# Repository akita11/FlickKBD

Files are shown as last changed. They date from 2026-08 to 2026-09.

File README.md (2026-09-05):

# FlickKBD

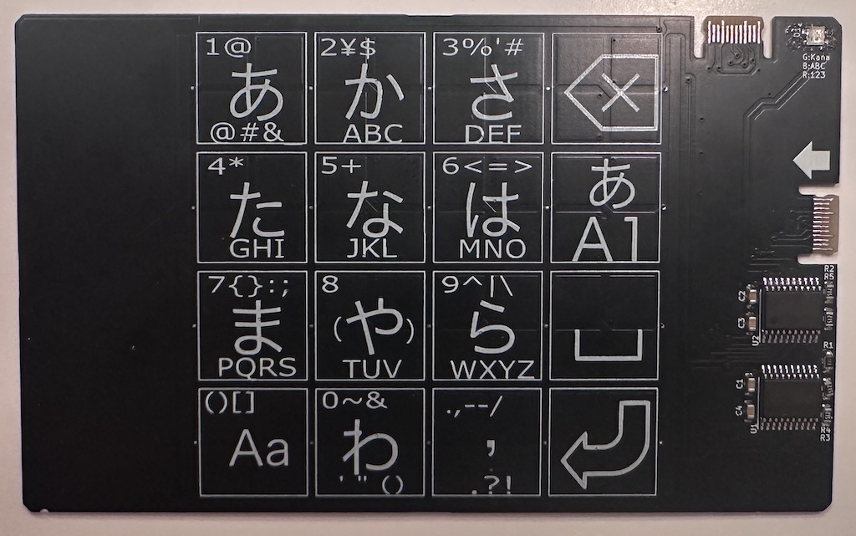
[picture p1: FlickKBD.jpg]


静電容量式タッチ検出を使った名刺サイズのフリック入力キーボードです。PC等にUSB(Type-C)で接続し、キーボードとして使うことができます。
かな（ローマ字入力）、英字、数字の3つのモードがあります。

※感度・入力速度はサポートページ内の動画からご確認ください。スマホのフリック入力ほどの実用性はありませんのでご了承ください。またPC等側のキーボードの設定（英字キーボード等）によっては、表示されているものと異なる文字が入力されることがあります。またタッチ検出の補正動作によって、非タッチ時にタッチが検出されてLEDが消灯している場合は、少し待つとLEDが点灯して入力できるようになります。

[動作原理と使用例（動画）(ProtoPedia)](https://protopedia.net/prototype/9148)

## 使い方

本機のUSB Type-Cコネクタ（基板と一体化）にUSB Type-Cケーブルを刺し、PC等に接続します。
PC等からはUSBキーボードとして認識されます。
（本機には2つのUSBコネクタがありますが、どちらでもOKです）

### 文字入力

やや強めにタッチしつつゆっくり移動させてフリック入力ができます。
（カッコ内は、左上のキーの場合の入力される文字例）

- タッチのみ: 基本文字（"a"）
- タッチ後、左にマス目の半分ほど移動：左フリック（"i"）
- タッチ後、上にマス目の半分ほど移動：上フリック（"u"）
- タッチ後、右にマス目の半分ほど移動：上フリック（"e"）
- タッチ後、下にマス目の半分ほど移動：上フリック（"o"）

LED表示は以下の意味で、タッチやフリック動作の検出状況を確認できます。
- 非タッチ時に点灯
- タッチ時に消灯
- 左or右フリック検出時に1回点滅
- 上or下フリック検出時に2回点滅、

なお、かな（ローマ字）入力モード時に"A/a"キー（左下）を押してから（LEDがやや暗くなる）文字入力を行うと小文字が入力されます。（例："あ(a)"→"ぁ(xa)"

また、アルファベット入力モード時に"A/a"キー（左下）を押すと、大文字／小文字モードが切り替わります（小文字入力時はLEDがやや暗くなります）

### 入力モード

"あA1"キー（右端上から2つめ）を押すと、入力モードが切り替わり、以下のようにLEDの色が変わります。

- かな（ローマ字）入力モード: 緑
- アルファベット入力モード: 青
- 数字・記号入力モード: 赤

## プログラムの書き換え

ArduinoIDEに、[CH55xduino](https://github.com/DeqingSun/ch55xduino)をインストールし、2つのUSBコネクタからそれぞれのマイコン(CH552)に書き込みます。
事前に、TouchKey.{c,h}を、ArduinoIDEフォルダ内のCH55xduinoフォルダのTouchKey/srcにコピーしてださい（念のため、オリジナルのCH55xduinoの両ファイルはバックアップをとっておいてください）。
（Macの場合は、~/Library/Arduino15/packages/CH55xDuino/hardware/mcs51/0.0.26/libraries/TouchKey/src）
- USB Settingを"USER CODE w/128B USB RAM"に変更
- 上側のUSBコネクタ: FlickKBD.ino中の"#define DEV_R"をコメントアウトし、書き込み
- 右側のUSBコネクタ: FlickKBD.ino中の"#define DEV_R"を残して、書き込み

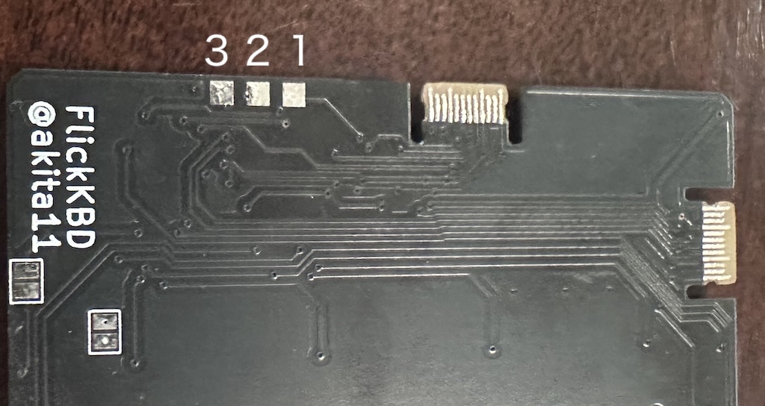
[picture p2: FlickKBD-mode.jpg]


なおブランクのCH552に初回書き込み時以外は、CH552を、以下の手順でダウンロードモードに設定してください。
- 右側のUSBコネクタ使用時: 裏面の上図の"1-2"間をジャンパ線等でショートした状態で右側USBコネクタに接続し、1秒ほど保持してからショートを解除する
- 上側のUSBコネクタ使用時: 裏面の上図の"2-3"間をジャンパ線等でショートした状態で右側USBコネクタに接続し、1秒ほど保持してからショートを解除する

## Author

Junichi Akita (akita@ifdl.jp / @akita11)

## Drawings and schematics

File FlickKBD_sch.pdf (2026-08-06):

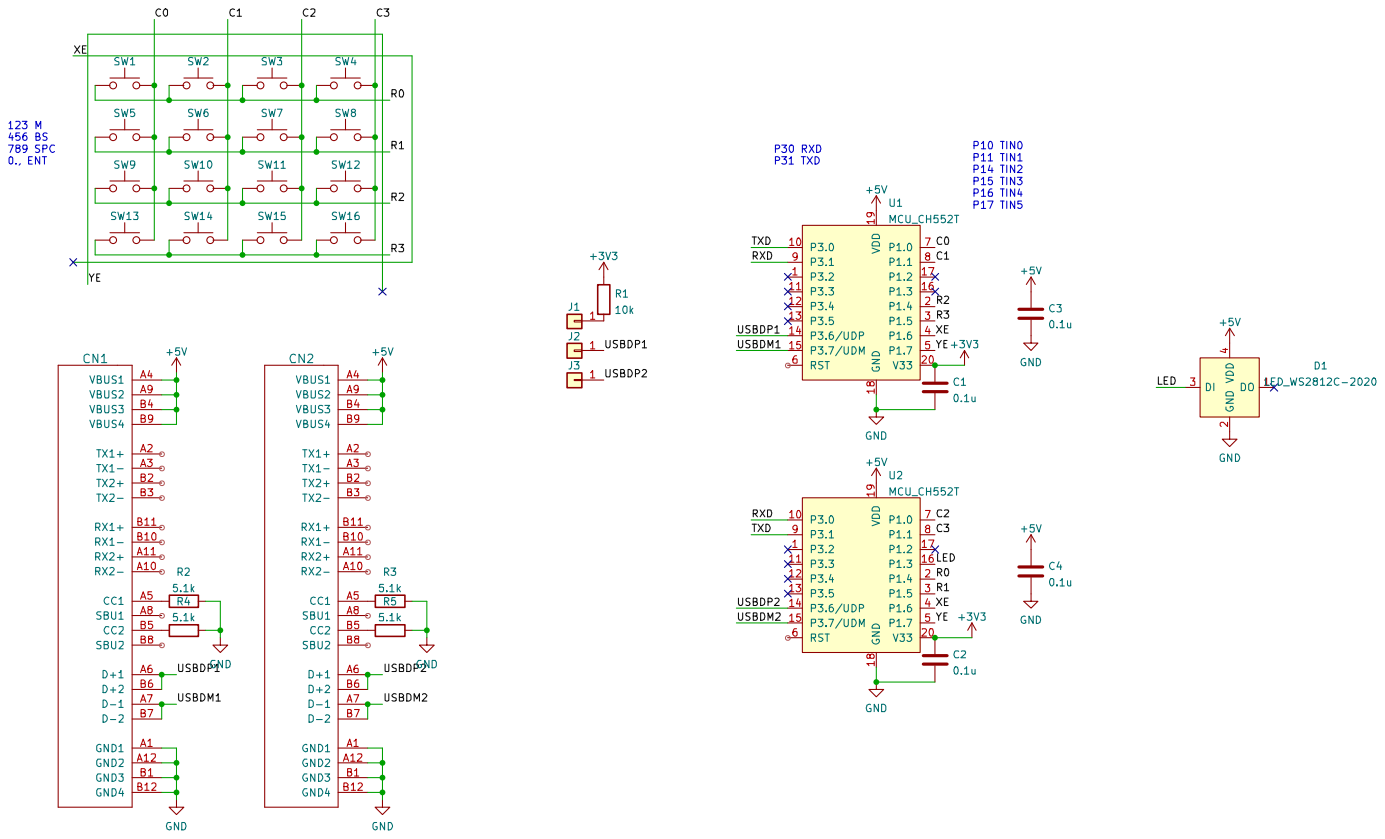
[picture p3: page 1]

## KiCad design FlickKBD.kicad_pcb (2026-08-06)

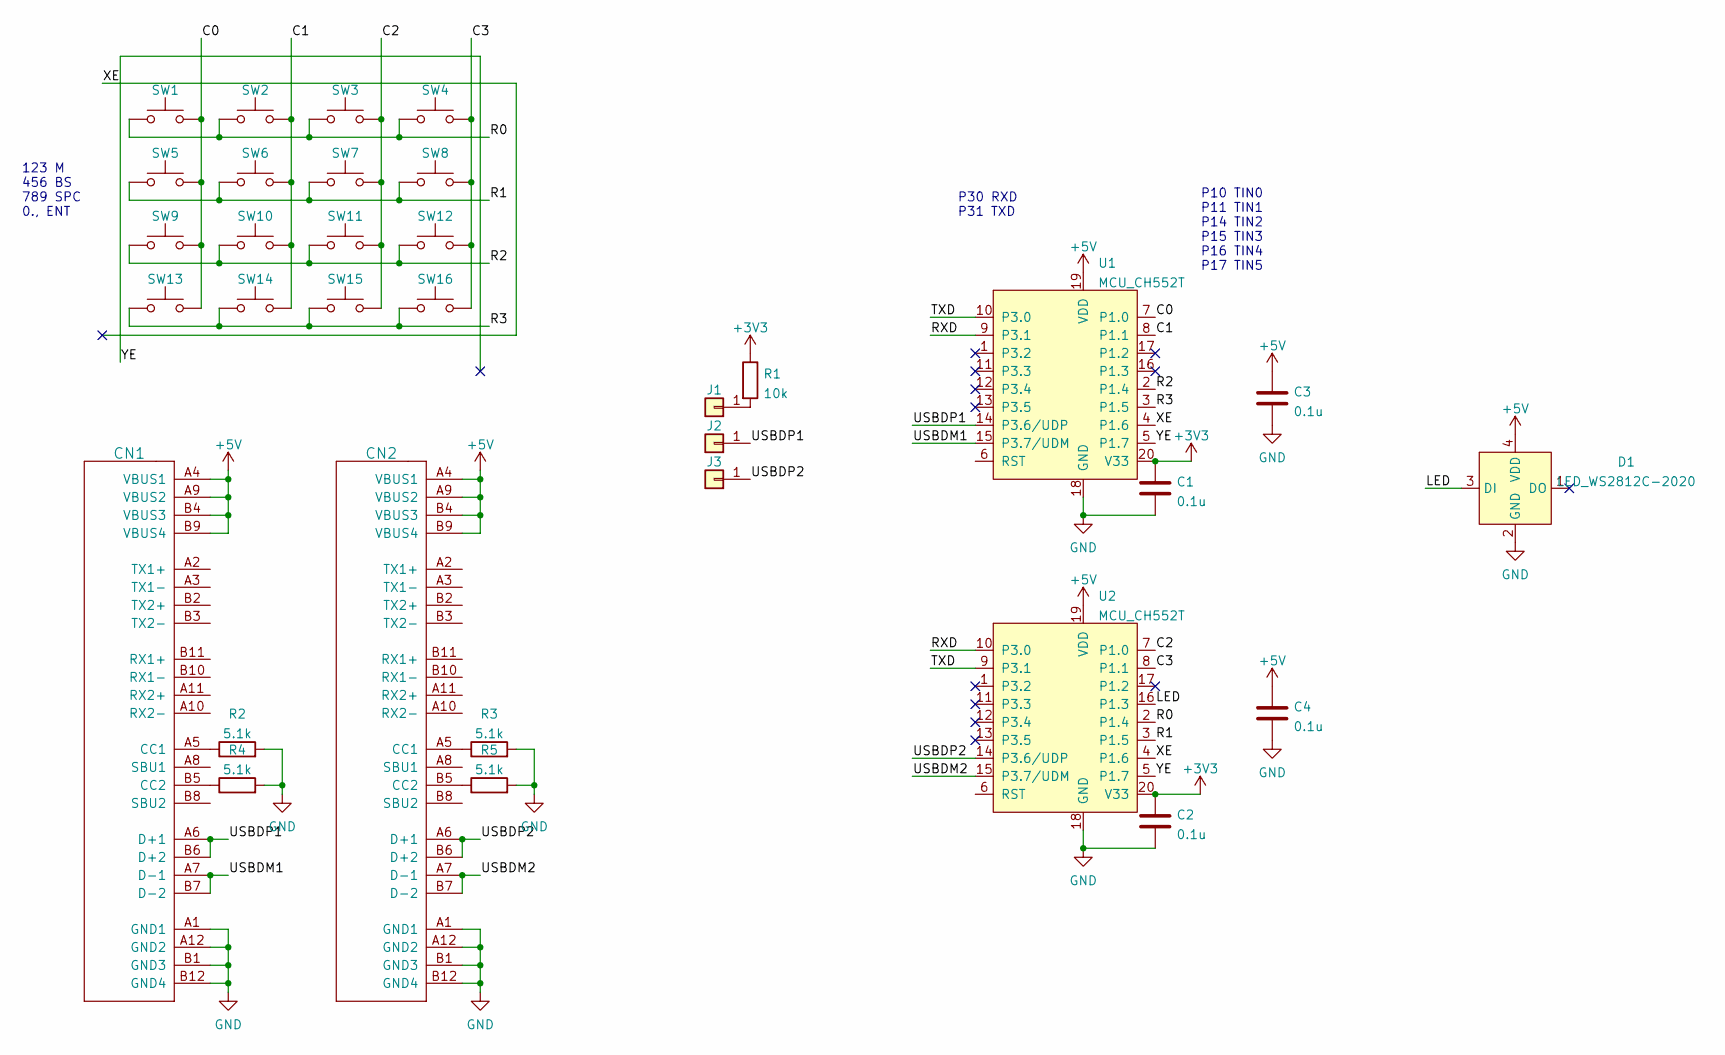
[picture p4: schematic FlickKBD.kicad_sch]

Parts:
C1, C2, C3, C4: 0.1u; C_0603_1608Metric
CN1, CN2: CON_USB-CPCBPLUG; USB-C_PCBPLUG
D1: LED_WS2812C-2020; LED_2020_4p
J1, J2, J3: Conn_01x01; Pad_SMD1.6mm
R1: 10k; R_0603_1608Metric
R2, R3, R4, R5: 5.1k; R_0603_1608Metric
SW1, SW2, SW3, SW4, SW5, SW6, SW7, SW8, SW9, SW10, SW11, SW12, SW13, SW14, SW15, SW16: SW_Push; SMD_Key_11mmX_p13mm
U1, U2: MCU_CH552T; TSSOP-20_4.4x6.5mm_P0.65mm

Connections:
+3V3: C1.1, C2.1, R1.1, U1.20 (V33), U2.20 (V33)
+5V: C3.1, C4.1, CN1.A4 (VBUS1), CN1.A9 (VBUS2), CN1.B4 (VBUS3), CN1.B9 (VBUS4), CN2.A4 (VBUS1), CN2.A9 (VBUS2), CN2.B4 (VBUS3), CN2.B9 (VBUS4), D1.4 (VDD), U1.19 (VDD), U2.19 (VDD)
/C0: SW1.1, SW5.1, SW9.1, SW13.1, U1.7 (P1.0)
/C1: SW2.1, SW6.1, SW10.1, SW14.1, U1.8 (P1.1)
/C2: SW3.1, SW7.1, SW11.1, SW15.1, U2.7 (P1.0)
/C3: SW4.1, SW8.1, SW12.1, SW16.1, U2.8 (P1.1)
/LED: D1.3 (DI), U2.16 (P1.3)
/R0: SW1.2, SW2.2, SW3.2, SW4.2, U2.2 (P1.4)
/R1: SW5.2, SW6.2, SW7.2, SW8.2, U2.3 (P1.5)
/R2: SW9.2, SW10.2, SW11.2, SW12.2, U1.2 (P1.4)
/R3: SW13.2, SW14.2, SW15.2, SW16.2, U1.3 (P1.5)
/RXD: U1.9 (P3.1), U2.10 (P3.0)
/TXD: U1.10 (P3.0), U2.9 (P3.1)
/USBDM1: CN1.A7 (D-1), CN1.B7 (D-2), U1.15 (P3.7/UDM)
/USBDM2: CN2.A7 (D-1), CN2.B7 (D-2), U2.15 (P3.7/UDM)
/USBDP1: CN1.A6 (D+1), CN1.B6 (D+2), J2.1, U1.14 (P3.6/UDP)
/USBDP2: CN2.A6 (D+1), CN2.B6 (D+2), J3.1, U2.14 (P3.6/UDP)
/XE: U1.4 (P1.6), U2.4 (P1.6); also elsewhere on the board
/YE: U1.5 (P1.7), U2.5 (P1.7); also elsewhere on the board
GND: C1.2, C2.2, C3.2, C4.2, CN1.A1 (GND1), CN1.A12 (GND2), CN1.B1 (GND3), CN1.B12 (GND4), CN2.A1 (GND1), CN2.A12 (GND2), CN2.B1 (GND3), CN2.B12 (GND4), D1.2 (GND), R2.2, R3.2, R4.2, R5.2, U1.18 (GND), U2.18 (GND)
unnamed: CN1.A5 (CC1), R2.1
unnamed: CN1.B5 (CC2), R4.1
unnamed: CN2.A5 (CC1), R3.1
unnamed: CN2.B5 (CC2), R5.1
unnamed: J1.1, R1.2

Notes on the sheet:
P10 TIN0 P11 TIN1 P14 TIN2 P15 TIN3 P16 TIN4 P17 TIN5
123 M 456 BS 789 SPC 0., ENT
P30 RXD P31 TXD

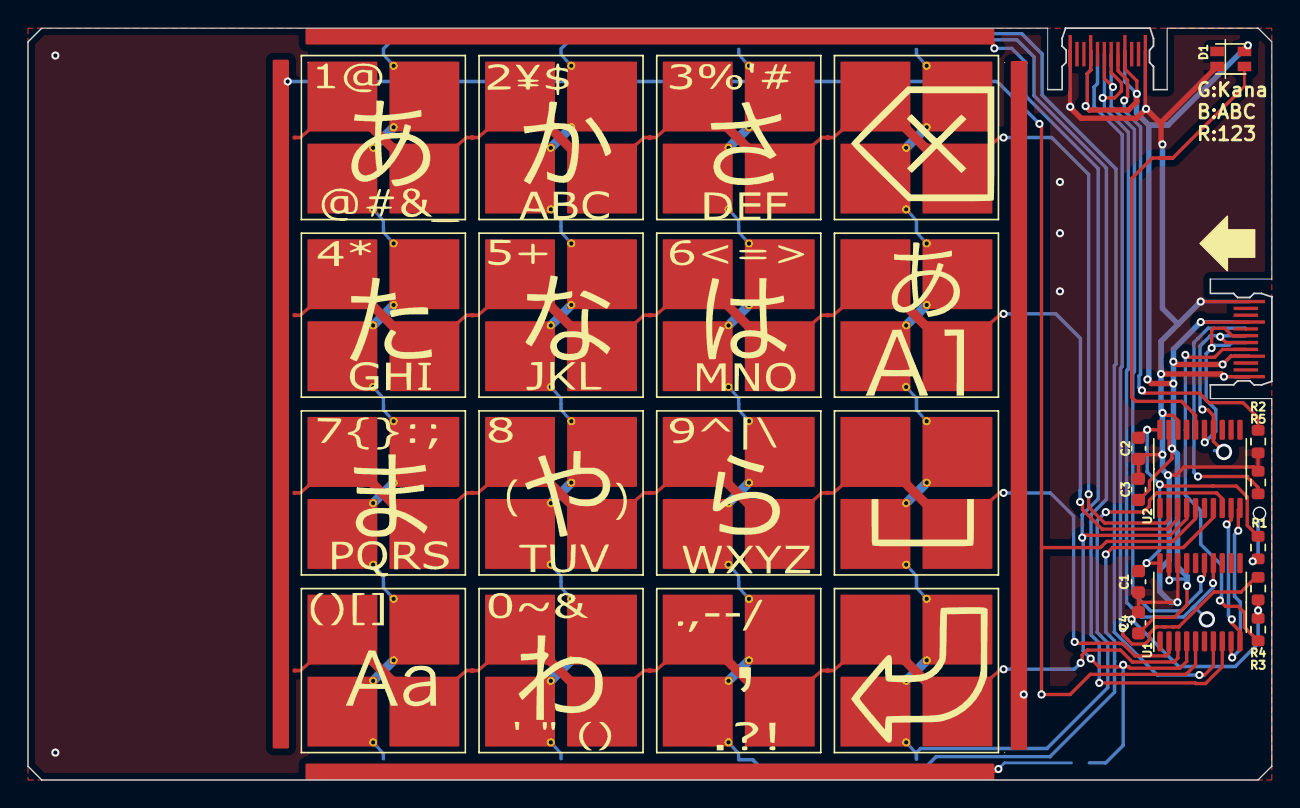
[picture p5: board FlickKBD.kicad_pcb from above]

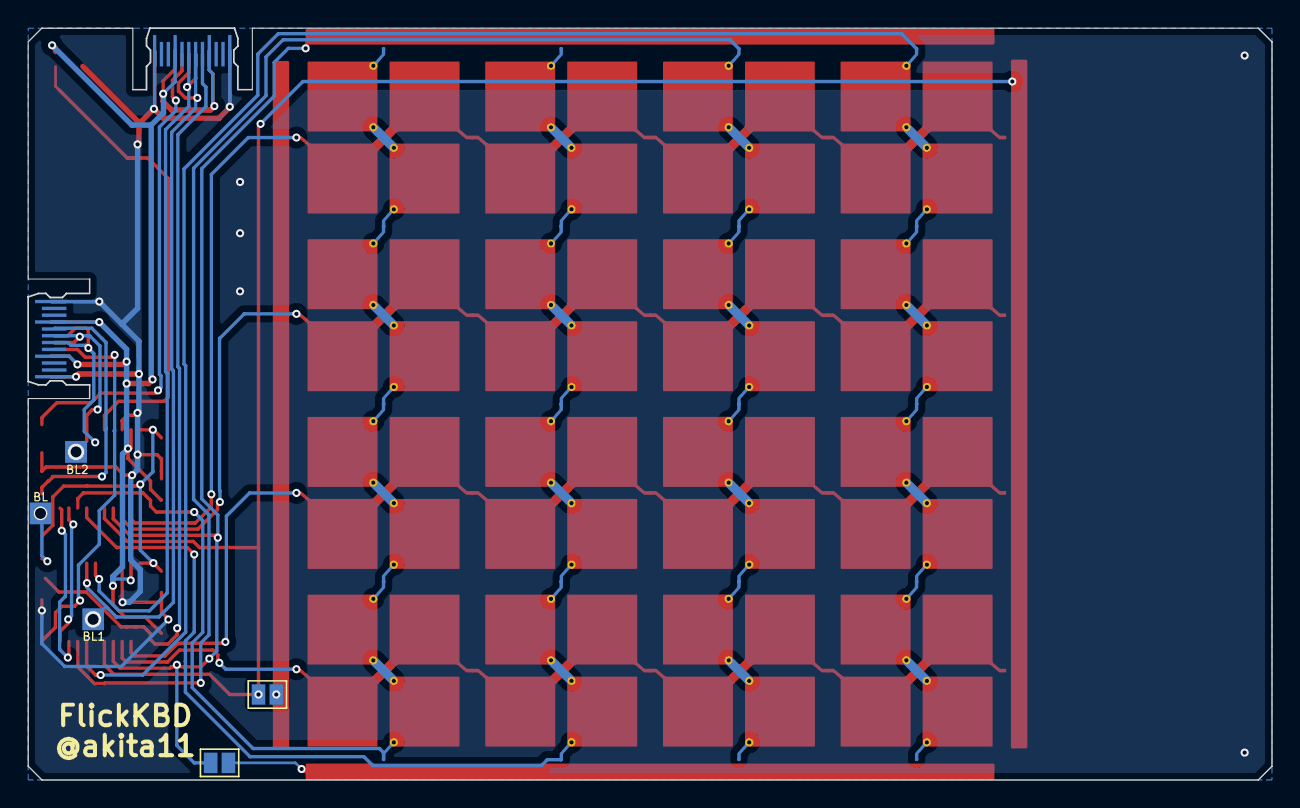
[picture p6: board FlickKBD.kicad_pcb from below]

Board: 2 copper layers, 91.0 x 55.0 mm, 35 parts (5 on the bottom side), 25 nets.

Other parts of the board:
JP1, JP2: Jumper_2_Open; SolderJumper-2_P1.3mm_Open_Pad1.0x1.5mm

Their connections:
/XE: JP1.1 (A); also elsewhere on the board
/YE: JP2.1 (A); also elsewhere on the board

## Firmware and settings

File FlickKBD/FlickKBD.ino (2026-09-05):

//#define DEV_R // for 1st CH552 (U2), with LED
#define USBKBD
// when building without USBKBD defined, src/userUsbHidKeyboard must be moved outside the Sketch folder.
//#define DEBUG // for touch parameter tuning

#include <TouchKey.h>

#ifdef DEV_R
#include <WS2812.h>
__xdata uint8_t ledData[3];
void setLED(uint8_t r, uint8_t g, uint8_t b){
  set_pixel_for_GRB_LED(ledData, 0, r, g, b);
  neopixel_show_P1_3(ledData, 3);
}
#endif

// 文字モード: ローマ字かな -> アルファベット -> 数字 の循環トグル (C3/R1)
#define MODE_KANA  0
#define MODE_ALPHA 1
#define MODE_NUM   2
uint8_t charMode = MODE_KANA;
// アルファベットモード:大文字(1)/小文字(0)、かなモード:通常(1い)/小文字モード(0)
// (どちらもC0/R3で切替、LEDは明(1)/暗(0))
uint8_t altKeyUpper = 1;

#ifdef DEV_R
#define LED_BRIGHT 10
#define LED_DIM     2

// 普段点灯するモード色 (かな=緑/アルファベット=青/数字=赤)、
// かな/アルファベットモードはaltKeyUpperで明暗
void showIdleLED(){
  uint8_t bright = ((charMode == MODE_ALPHA || charMode == MODE_KANA) && !altKeyUpper) ? LED_DIM : LED_BRIGHT;
  if (charMode == MODE_KANA) setLED(0, bright, 0);
  else if (charMode == MODE_ALPHA) setLED(0, 0, bright);
  else setLED(bright, 0, 0);
}

// タッチ検出時: 消灯
void ledTouchOff(){
  setLED(0, 0, 0);
}

// 左右フリック=1回、上下フリック=2回、普段の色でcount回点滅し、
// (タッチ中のため)消灯状態に戻る。離す時にshowIdleLED()で点灯に戻す。
void blinkLED(uint8_t count){
  uint8_t bright = ((charMode == MODE_ALPHA || charMode == MODE_KANA) && !altKeyUpper) ? LED_DIM : LED_BRIGHT;
  for (uint8_t i = 0; i < count; i++){
    if (charMode == MODE_KANA) setLED(0, bright, 0);
    else if (charMode == MODE_ALPHA) setLED(0, 0, bright);
    else setLED(bright, 0, 0);
    delay(80);
    setLED(0, 0, 0u);
    delay(80);
  }
}
#else
void showIdleLED(){}
void ledTouchOff(){}
void blinkLED(uint8_t count){}
#endif

#ifdef USBKBD
  #ifndef USER_USB_RAM
  #error "This example needs to be compiled with a USER USB setting"
  #endif
  #include "src/userUsbHidKeyboard/USBHIDKeyboard.h"
#endif

//       T0 T1 T2 T3 T4 T5 
// DevU: C0 C1 R2 R3 XE YE (USB conn: UP)
// DevR: C2 C3 R0 R1 XE YE (USB conn: RIGHT)

// X------------------ (U4/R4)
//         U0 U1 R0 R1 
// Y       C0 C1 C2 C3 Y(U5/R5)
// | R2 R0       r  r  |
// | R3 R1       r  r  |
// | U2 R2 u  u        |
// | U3 R3 u  u        |
// X------------------

// ============================================================
// TouchKey.c への修正まとめ (2025-07-17)
//
// 【問題1】TIN5/TIN6 が非タッチ時でもタッチ状態のままになる
//   原因A: TouchKey_begin() でポーリングモードにより baseline を初期化するが、
//          ISR 連続スキャンモードでの計測値と TIN5/TIN6 だけ大きくずれる
//          (TIN5: +659差、TIN6: -258差)。TIN6 は起動直後から touchThreshold を
//          超えた状態でスタートし、以後ずっとタッチ判定になる。
//   原因B: baseline の追跡速度 (noiseHalfDelta/noiseCountLimit = 0.2 units/cycle) が
//          TIN5/TIN6 の環境ドリフト速度 (~6 units/cycle) に追いつかない。
//
//   修正1 (TouchKey_begin): IE_TKEY = 1 で ISR を起動した後、2完全スキャンサイクル
//          (12 ISR イベント) 待機し、ISR モードの実計測値で baseline を上書きする。
//          これにより初期ズレが解消され、以後の漸進的ドリフトは Case1 で追跡できる。
//
//   修正2 (TouchKey_Process): touchStuckLimit サイクル (デフォルト500 ≒ 6秒) 以上
//          タッチ状態が続いた場合、baseline を raw に向けて通常より大きく移動させる
//          強制補正機構 (スタックタッチ回復) を追加。修正1 のフォールバックとして機能。
//
// 【問題2】TIN0-3 でタッチを離した後、数秒間タッチ検知が続く
//   原因: タッチ中に Case2 の slow tracking が baseline を少し下方へ移動させる。
//         指を離すと raw はすぐにアンビエントへ戻り raw > baseline (diff > 0) になるが、
//         解除条件が "mdiff > 0 && mdiff < releaseThreshold" であるため、
//         mdiff = 0 の状態では解除条件を満たせない。
//         以後 Case2 upward tracking が baseline をゆっくり引き上げ (~0.2 units/cycle)、
//         数秒後にノイズで mdiff が 1 になって初めて解除される。
//
//   修正3 (TouchKey_Process): タッチ中 (touchKeyPressed セット済み) に diff > 0
//          (raw が baseline を上回った) を検出したとき即座に解除し、baseline を raw に
//          スナップする。CH552 ではタッチ = raw 低下なので、raw が baseline を超えた
//          時点でタッチ終了は確実。タッチ中に raw が baseline を超えるほどの
//          ノイズは実質起きないため誤検出のリスクはない。
// ============================================================

extern volatile __xdata uint16_t touchRawValue[];
extern __xdata uint16_t touchBaseline[];
extern __xdata uint16_t touchMaxHalfDelta;
extern __xdata uint16_t touchThreshold[6];
extern __xdata uint16_t releaseThreshold[6];
extern __xdata uint16_t touchStuckLimit[6];
extern __xdata uint8_t touchNextCalibrateCycleCounter;
extern __xdata uint8_t touchCycleCounter;

uint8_t touchU = 0;
uint8_t touchR = 0;

uint16_t touch_c = 0;
uint16_t touch_p = 0;

#define COL0 0x001
#define COL1 0x002
#define COL2 0x004
#define COL3 0x008
#define COLY 0x100
#define ROW0 0x010
#define ROW1 0x020
#define ROW2 0x040
#define ROW3 0x080
#define ROWX 0x200
#define COLALL (COL0 | COL1 | COL2 | COL3 | COLY)
#define ROWALL (ROW0 | ROW1 | ROW2 | ROW3 | ROWX)

void setup() {
  // 起動直後、他の初期化より前に明示的にモード色(かな=緑,LED_BRIGHT)を点灯し、
  // 未初期化状態のLEDが誤って明るく見える時間を最小化する
  showIdleLED();
#ifdef DEV_R
  pinMode(13, OUTPUT);
  TouchKey_begin( (1 << 0) | (1 << 1) | (1 << 2) | (1 << 3) | (1 << 4) | (1 << 5) ); //Enable all 6 channels: TIN0(P1.0), TIN1(P1.1), TIN2(P1.4), TIN3(P1.5), TIN4(P1.6), TIN5(P1.7)
#else
  TouchKey_begin( (1 << 0) | (1 << 1) | (1 << 2) | (1 << 3) | (1 << 4) | (1 << 5) ); //Enable all 6 channels: TIN0(P1.0), TIN1(P1.1), TIN2(P1.4), TIN3(P1.5), TIN4(P1.6), TIN5(P1.7)
//  TouchKey_begin( (1 << 0) | (1 << 1) | (1 << 2) | (1 << 3) ); //Enable all 6 channels: TIN0(P1.0), TIN1(P1.1), TIN2(P1.4), TIN3(P1.5)
#endif
#ifdef DEV_R
/*
  // for v1
  TouchKey_SetMaxHalfDelta(20);    //MHD=5, increase if sensor value are more noisy
  TouchKey_SetNoiseHalfDelta(2);    //NHD=2, If baseline need to adjust at higher rate, increase this value
  TouchKey_SetNoiseCountLimit(10);  //NCL=10, If baseline need to adjust faster, increase this value
//  TouchKey_SetFilterDelayLimit(5);  //FDL=5, make overall adjustment slower
  TouchKey_SetTouchThreshold(1500);  //100, Bigger touch pad can use a bigger value
  TouchKey_SetReleaseThreshold(1000); //80, Smaller than touch threshold
  touchThreshold[4] = 1000; releaseThreshold[4] = 700;
  touchThreshold[5] = 1000; releaseThreshold[5] = 700;
*/
  TouchKey_SetMaxHalfDelta(10);    //MHD=5, increase if sensor value are more noisy
  TouchKey_SetNoiseHalfDelta(2);    //NHD=2, If baseline need to adjust at higher rate, increase this value
  TouchKey_SetNoiseCountLimit(10);  //NCL=10, If baseline need to adjust faster, increase this value
  TouchKey_SetFilterDelayLimit(5);  //FDL=5, make overall adjustment slower
  TouchKey_SetTouchThreshold(250);  //100, Bigger touch pad can use a bigger value
  TouchKey_SetReleaseThreshold(240); //80, Smaller than touch threshold
  // 実測の結果、実タッチ振幅(約750-950)はドリフトのピーク(約900-2800、
  // セッションにより変動)と分離できないと判明。XE/YEは単独でキー押下に
  // ならない(下のCOLY/ROWX単独ガード)ため、方針転換: しきい値は他chと同じ
  // 250/240のまま(=検出漏れを避けるため実タッチ振幅より十分低く保つ)、
  // 誤検出(触れていなくても検出)は許容する。
  // スタックタッチ回復だけXE/YEを早める(デフォルト500サイクル≒5-6秒
  // -> 約40サイクル≒0.4秒)ことで、ドリフトによる「触れっぱなし」状態を
  // 短時間で自動的に解消する。ch0-3は変更しない。
  touchStuckLimit[4] = 40;
  touchStuckLimit[5] = 40;
#else
  // for DEV_U
/*
  // for v1
  TouchKey_SetMaxHalfDelta(20);    //5, increase if sensor value are more noisy
  TouchKey_SetNoiseHalfDelta(2);    //2, If baseline need to adjust at higher rate, increase this value
  TouchKey_SetNoiseCountLimit(10);  //10, If baseline need to adjust faster, increase this value
//  TouchKey_SetFilterDelayLimit(50);  //5, make overall adjustment slower
  TouchKey_SetTouchThreshold(1500);  //100, Bigger touch pad can use a bigger value
  TouchKey_SetReleaseThreshold(1000); //80, Smaller than touch threshold
  touchThreshold[4] = 1000; releaseThreshold[4] = 700;
  touchThreshold[5] = 1000; releaseThreshold[5] = 700;
  */
  TouchKey_SetMaxHalfDelta(10);    //5, increase if sensor value are more noisy
  TouchKey_SetNoiseHalfDelta(2);    //2, If baseline need to adjust at higher rate, increase this value
  TouchKey_SetNoiseCountLimit(10);  //10, If baseline need to adjust faster, increase this value
  TouchKey_SetFilterDelayLimit(5);  //5, make overall adjustment slower
  TouchKey_SetTouchThreshold(250);  //100, Bigger touch pad can use a bigger value
  TouchKey_SetReleaseThreshold(240); //80, Smaller than touch threshold
  // 実測の結果、実タッチ振幅(約750-950)はドリフトのピーク(約900-2800、
  // セッションにより変動)と分離できないと判明。XE/YEは単独でキー押下に
  // ならない(下のCOLY/ROWX単独ガード)ため、方針転換: しきい値は他chと同じ
  // 250/240のまま(=検出漏れを避けるため実タッチ振幅より十分低く保つ)、
  // 誤検出(触れていなくても検出)は許容する。
  // スタックタッチ回復だけXE/YEを早める(デフォルト500サイクル≒5-6秒
  // -> 約40サイクル≒0.4秒)ことで、ドリフトによる「触れっぱなし」状態を
  // 短時間で自動的に解消する。ch0-3は変更しない。
  touchStuckLimit[4] = 40;
  touchStuckLimit[5] = 40;
#endif

  Serial0_begin(9600);
#ifdef USBKBD
  USBInit();
#endif
  showIdleLED();
}

uint8_t st = 0;
uint8_t key1stC = 0, key1stR = 0;
uint8_t keyOffset = 0;

// keyPos (= key1stC + key1stR*4) の特殊キー
#define KP_BS    3  // C3/R0 Backspace
#define KP_MODE  7  // C3/R1 文字モード切替
#define KP_SPC  11  // C3/R2 Space
#define KP_CASE 12  // C0/R3 大文字/小文字切替
#define KP_PUNCT 14 // C2/R3 , . ? !
#define KP_ENT  15  // C3/R3 Enter

// かなモード (ローマ字入力): 子音+母音
char consonant[] = {' ', 'k', 's', '<', 't', 'n', 'h', '*', 'm', 'y', 'r', ' ', 'C', 'w', '?', 'E'};
char vowel[] = {'a', 'i', 'u', 'e', 'o'};

// 数字モードのタッチ(フリック無し)出力。一般的なテンキー配列 (1,2,3/4,5,6/7,8,9/0)
char digitChar[16] = {'1','2','3',0, '4','5','6',0, '7','8','9',0, 0,'0',0,0};

// アルファベットモードのフリック出力 [keyPos][左/上/右/下]
char alphaLetters[16][4] = {
  {0,0,0,0},           // C0R0 (1)
  {'A','B','C',0},     // C1R0 (2)
  {'D','E','F',0},     // C2R0 (3)
  {0,0,0,0},           // C3R0
  {'G','H','I',0},     // C0R1 (4)
  {'J','K','L',0},     // C1R1 (5)
  {'M','N','O',0},     // C2R1 (6)
  {0,0,0,0},           // C3R1
  {'P','Q','R','S'},   // C0R2 (7)
  {'T','U','V',0},     // C1R2 (8)
  {'W','X','Y','Z'},   // C2R2 (9)
  {0,0,0,0},           // C3R2
  {0,0,0,0},           // C0R3
  {0,0,0,0},           // C1R3 (0)
  {0,0,0,0},           // C2R3
  {0,0,0,0},           // C3R3
};

// 数字モードのフリック出力 [keyPos][左/上/右/下]
// ¥ はASCIIで表現できないため、代わりにバックスラッシュ(\)を使用
char numSymbols[16][4] = {
  {'@',0,0,0},           // C0R0 (1)
  {'\\','$',0,0},        // C1R0 (2)
  {'%','\'','#',0},      // C2R0 (3)
  {0,0,0,0},             // C3R0
  {'*',0,0,0},           // C0R1 (4)
  {'+',0,0,0},           // C1R1 (5)
  {'<','=','>',0},       // C2R1 (6)
  {0,0,0,0},             // C3R1
  {'{','}',':',';'},     // C0R2 (7)
  {0,0,0,0},             // C1R2 (8)
  {'^','|','\\',0},      // C2R2 (9)
  {0,0,0,0},             // C3R2
  {0,0,0,0},             // C0R3
  {'~','&',0,0},         // C1R3 (0)
  {0,0,0,0},             // C2R3
  {0,0,0,0},             // C3R3
};

void loop() {
  TouchKey_Process();
  uint8_t touchResult = TouchKey_Get();
#ifdef DEBUG
  for (uint8_t i = 0; i < 6; i++) {
    if (touchResult & (1 << i)) {
      if (i == 0 || i == 1) USBSerial_print(" C ");
      else if (i == 2 || i == 3) USBSerial_print(" R ");
      else if (i == 4) USBSerial_print(" X ");
      else if (i == 5) USBSerial_print(" Y ");
    } else {
      USBSerial_print(" _ ");
    }
  }
  for (uint8_t i = 0; i < 6; i++) {
  	int16_t diff = touchRawValue[i] - touchBaseline[i];
    USBSerial_print(touchRawValue[i]); USBSerial_print("/");
    USBSerial_print(touchBaseline[i]); USBSerial_print(":");
    USBSerial_print(diff); USBSerial_print(" ");
  }
  USBSerial_println("");
  /*
  for (uint8_t i = 4; i < 6; i++) {
    USBSerial_print(touchRawValue[i]); USBSerial_print(","); USBSerial_print(touchBaseline[i]); USBSerial_print(",");
  }
  USBSerial_println("");
  */
#endif
#ifdef DEV_R
  touchR = touchResult;
#else
  touchU = touchResult;
#endif
  // send touchResult another CH552
  Serial0_write(touchResult);

  if (Serial0_available())
  // get touchResult from another CH552
#ifdef DEV_R
  touchU = Serial0_read();
#else
  touchR = Serial0_read();
#endif

// DevU: C0 C1 R2 R3 XE YE (USB conn: UP)
// DevR: C2 C3 R0 R1 XE YE (USB conn: RIGHT)
  touch_c = 0;
  if (touchU & 0x01) touch_c |= COL0;
  if (touchU & 0x02) touch_c |= COL1;
  if (touchR & 0x01) touch_c |= COL2;
  if (touchR & 0x02) touch_c |= COL3;
  if (touchU & 0x20 || touchR & 0x20) touch_c |= COLY;
  if (touchR & 0x04) touch_c |= ROW0;
  if (touchR & 0x08) touch_c |= ROW1;
  if (touchU & 0x04) touch_c |= ROW2;
  if (touchU & 0x08) touch_c |= ROW3;
  if (touchU & 0x10 || touchR & 0x10) touch_c |= ROWX;
#ifndef USBKBD
 #ifdef DEBUG
 #else
/*
  if (touch_c & COL0) USBSerial_print("C0 "); else USBSerial_print("-- ");
  if (touch_c & COL1) USBSerial_print("C1 "); else USBSerial_print("-- ");
  if (touch_c & COL2) USBSerial_print("C2 "); else USBSerial_print("-- ");
  if (touch_c & COL3) USBSerial_print("C3 "); else USBSerial_print("-- ");
  if (touch_c & COLY) USBSerial_print("Y"); else USBSerial_print("-");
  USBSerial_print(" : ");
  if (touch_c & ROW0) USBSerial_print("R0 "); else USBSerial_print("-- ");
  if (touch_c & ROW1) USBSerial_print("R1 "); else USBSerial_print("-- ");
  if (touch_c & ROW2) USBSerial_print("R2 "); else USBSerial_print("-- ");
  if (touch_c & ROW3) USBSerial_print("R3 "); else USBSerial_print("-- ");
  if (touch_c & ROWX) USBSerial_print("X"); else USBSerial_print("-");
  USBSerial_println("");
  */
 #endif
#endif
  uint8_t cntR = 0, cntC = 0;
  if (touch_c & COLY) cntC++;
  if (touch_c & COL0) cntC++;
  if (touch_c & COL1) cntC++;
  if (touch_c & COL2) cntC++;
  if (touch_c & COL3) cntC++;
  if (touch_c & ROWX) cntR++;
  if (touch_c & ROW0) cntR++;
  if (touch_c & ROW1) cntR++;
  if (touch_c & ROW2) cntR++;
  if (touch_c & ROW3) cntR++;

//    C0 C1 C2 C3
// R0 A  KA SA BS
// R1 TA NA HA Typeset
// R2 MA YA RA SPC
// R3 Cp WA ?. ENT

// Typeset: Kana/Alphabet/Number 循環トグル、LEDはモードごとに緑/青/赤
// BS : Backspace ("[BS]")
// Cp : アルファベットモードの Upper/Lower Case 切替 (LED明:大文字/暗:小文字)
// ?. : 押す/左/上/右フリックの順に , . ? !

  // COLY/ROWXは実キーに隣接するフリック検出専用の仮想エッジセンサーであり、
  // これ単独(COLYのみ/ROWXのみ)でのタッチ開始は無視する。
  // XE/YEチャンネルのドリフトでCOLYとROWXが同時に誤検出されたとき、
  // 実キーではないのにC0R0(あ)扱いされてしまう誤動作を防ぐ。
  if (st == 0 && cntC == 1 && cntR == 1 &&
      (touch_c & COLALL) != COLY && (touch_c & ROWALL) != ROWX){
    st = 1;
    switch(touch_c & COLALL){
      case COL0 : key1stC = 0; break;
      case COL1 : key1stC = 1; break;
      case COL2 : key1stC = 2; break;
      case COL3 : key1stC = 3; break;
      default: key1stC = 0; break;
    }
    switch(touch_c & ROWALL){
      case ROW0 : key1stR = 0; break;
      case ROW1 : key1stR = 1; break;
      case ROW2 : key1stR = 2; break;
      case ROW3 : key1stR = 3; break;
      default: key1stR = 0; break;
    }
    keyOffset = 0;
    ledTouchOff();
  }

  if (st == 1){
//    USBSerial_print(cntC); USBSerial_print("/"); USBSerial_println(cntR);
    if (cntC == 2){
      // L/R flicked
      if (key1stC == 0 && (touch_c & COLY)) keyOffset = 1;
      else if (key1stC == 0 && (touch_c & COL1)) keyOffset = 3;
      else if (key1stC == 1 && (touch_c & COL0)) keyOffset = 1;
      else if (key1stC == 1 && (touch_c & COL2)) keyOffset = 3;
      else if (key1stC == 2 && (touch_c & COL1)) keyOffset = 1;
      else if (key1stC == 2 && (touch_c & COL3)) keyOffset = 3;
      else if (key1stC == 3 && (touch_c & COL2)) keyOffset = 1;
      st = 2;
      blinkLED(1);
    }
    else if (cntR == 2){
//      USBSerial_print(key1stR); USBSerial_print("--"); USBSerial_println(touch_c, HEX);
      // U/D flicked
      if (key1stR == 0 && (touch_c & ROWX)) keyOffset = 2;
      else if (key1stR == 0 && (touch_c & ROW1)) keyOffset = 4;
      else if (key1stR == 1 && (touch_c & ROW0)) keyOffset = 2;
      else if (key1stR == 1 && (touch_c & ROW2)) keyOffset = 4;
      else if (key1stR == 2 && (touch_c & ROW1)) keyOffset = 2;
      else if (key1stR == 2 && (touch_c & ROW3)) keyOffset = 4;
      else if (key1stR == 3 && (touch_c & ROW2)) keyOffset = 2;
      st = 2;
      blinkLED(2);
    }
  }

  if (st != 0 && cntC == 0 && cntR == 0){
    // released
    uint8_t keyPos = key1stC + key1stR * 4;
    char outPrefix = 0, out1 = 0, out2 = 0;
    uint8_t sendBS = 0, sendSPC = 0, sendENT = 0;

    if (keyPos == KP_BS) {
      sendBS = 1;
    } else if (keyPos == KP_MODE) {
      if (st == 1) {
        charMode++;
        if (charMode > MODE_NUM) charMode = MODE_KANA;
      }
    } else if (keyPos == KP_SPC) {
      sendSPC = 1;
    } else if (keyPos == KP_ENT) {
      sendENT = 1;
    } else if (keyPos == KP_CASE) {
      if (charMode == MODE_NUM) {
        // 数字モード: タッチ/左/上/右/下 = ( ) [ ] 無割当
        switch (keyOffset) {
          case 0: out2 = '('; break;
          case 1: out2 = ')'; break;
          case 2: out2 = '['; break;
          case 3: out2 = ']'; break;
          default: break;
        }
      } else if (st == 1) {
        altKeyUpper = !altKeyUpper;
      }
    } else if (keyPos == KP_PUNCT) {
      if (charMode == MODE_NUM) {
        // 数字モード: タッチ/左/上/右/下 = . , - / 無割当
        switch (keyOffset) {
          case 0: out2 = '.'; break;
          case 1: out2 = ','; break;
          case 2: out2 = '-'; break;
          case 3: out2 = '/'; break;
          default: break;
        }
      } else {
        // 押す/左/上/右フリックの順に , . ? ! (下フリックは未割当)
        switch (keyOffset) {
          case 0: out2 = ','; break;
          case 1: out2 = '.'; break;
          case 2: out2 = '?'; break;
          case 3: out2 = '!'; break;
          default: break;
        }
      }
    } else if (charMode == MODE_KANA) {
      if (keyPos == 9 && keyOffset == 1) {
        // C1R2(YA行) 左フリックのみ ( に差し替え
        out2 = '(';
      } else if (keyPos == 9 && keyOffset == 3) {
        // C1R2(YA行) 右フリックのみ ) に差し替え
        out2 = ')';
      } else if (keyPos == 13) {
        // C1R3(WA行): タッチ=wa, 左=wo, 上=n, 右=- , 下=無割当
        switch (keyOffset) {
          case 0: out1 = 'w'; out2 = 'a'; break;
          case 1: out1 = 'w'; out2 = 'o'; break;
          case 2: out2 = 'n'; break;
          case 3: out2 = '-'; break;
          default: break;
        }
      } else {
        out1 = consonant[keyPos];
        if (out1 == ' ') out1 = 0;
        out2 = vowel[keyOffset];
      }
      // 小文字モード(C0/R3でトグル、altKeyUpper==0)時、
      // 「あいうえお」「つ」「やゆよ」には冒頭に x を前置(ぁぃぅぇぉ/っ/ゃゅょ)
      if (!altKeyUpper) {
        if (keyPos == 0 ||
            (keyPos == 4 && keyOffset == 2) ||
            (keyPos == 9 && keyOffset != 1 && keyOffset != 3)) {
          outPrefix = 'x';
        }
      }
    } else if (charMode == MODE_NUM) {
      if (keyOffset == 0) out2 = digitChar[keyPos];
      else out2 = numSymbols[keyPos][keyOffset - 1];
    } else if (keyPos == 0) {
      // C0R0 (アルファベット): タッチ/左/上/右/下 = @ # & _ -
      switch (keyOffset) {
        case 0: out2 = '@'; break;
        case 1: out2 = '#'; break;
        case 2: out2 = '&'; break;
        case 3: out2 = '_'; break;
        default: break; // 下フリックは無割当
      }
    } else if (keyPos == 13) {
      // C1R3 (アルファベット、1つ左シフト済): タッチ/左/上/右/下 = ' " ( ) -
      switch (keyOffset) {
        case 0: out2 = '\''; break;
        case 1: out2 = '"'; break;
        case 2: out2 = '('; break;
        case 3: out2 = ')'; break;
        default: break; // 下フリックは無割当
      }
    } else { // MODE_ALPHA (その他のキー、1つ左シフト済)
      // 元は左/上/右/下だった alphaLetters[keyPos][0..3] を、
      // そのままタッチ/左/上/右に前詰めし、下フリックは無割当にする
      if (keyOffset < 4) {
        out2 = alphaLetters[keyPos][keyOffset];
        if (out2 != 0 && !altKeyUpper) out2 = out2 - 'A' + 'a';
      }
    }
    //USBSerial_print(st); USBSerial_print("-"); USBSerial_print(key1stC); USBSerial_print("-"); USBSerial_print(key1stR); USBSerial_print("-"); USBSerial_println(keyOffset);
#ifdef USBKBD
    if (sendBS) { Keyboard_write(KEY_BACKSPACE); }
    else if (sendSPC) { Keyboard_write(' '); }
    else if (sendENT) { Keyboard_write(KEY_RETURN); }
    else {
      if (outPrefix != 0) Keyboard_write(outPrefix);
      if (out1 != 0) Keyboard_write(out1);
      if (out2 != 0) Keyboard_write(out2);
    }
#else
    if (sendBS) { USBSerial_println("[BS]"); }
    else if (sendSPC) { USBSerial_println("[SPC]"); }
    else if (sendENT) { USBSerial_println("[ENT]"); }
    else if (outPrefix != 0 || out1 != 0 || out2 != 0) {
      if (outPrefix != 0) USBSerial_print(outPrefix);
      if (out1 != 0) USBSerial_print(out1);
      USBSerial_println(out2);
    }
#endif
    showIdleLED(); // 離したのでモード色の点灯に戻す
    st = 0;
  }
  delay(10);
}
